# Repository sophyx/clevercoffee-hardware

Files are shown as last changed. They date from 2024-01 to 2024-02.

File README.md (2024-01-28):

# Fork from [clevercoffee-hardware](https://github.com/rancilio-pid/clevercoffee-hardware)

Forked because I want to improve the routing of the minimal PCB. Original Readme:

# CleverCoffee Hardware 

<br>

KiCAD projects for breakout boards based on the ESP32 DevKitC v4 

* Minimal PCB with a smaller footprint and all unused GPIO-Pins on a separate header
* Development PCB with additional support for rotary encoder and dimmer circuit
* Experimental SMD variant of the minimal PCB with additional headers for the optional brew and steam LEDs
* Experimental SMD variant of the development PCB with a smaller footprint and wider spacing of the headers to be able to mount JST XH plugs

<br>
If you want to order PCBs yourself please keep in mind that the development boards are still a work in progress. The pinmapping for the features that are not yet on the minimal PCB is subject to change at any time.
<br>
<br>
For the latest revision of the minimal PCB just write us a message on our Discord.
<br>
<br>
If you want to create your own hardware based on our designs, please contact us beforehand to make sure you're not developing against an outdated revision. There may be unpublished changes not yet available in the repository.<br>
Also note that for regulatory and safety reasons we are not interested in designs with components operating at mains voltage.
<br>
<br>

Creative Commons Licence

<br>
<br>



This work is licensed under a <a rel="license" href="http://creativecommons.org/licenses/by-nc-sa/4.0/">Creative Commons Attribution-NonCommercial-ShareAlike 4.0 International License</a>

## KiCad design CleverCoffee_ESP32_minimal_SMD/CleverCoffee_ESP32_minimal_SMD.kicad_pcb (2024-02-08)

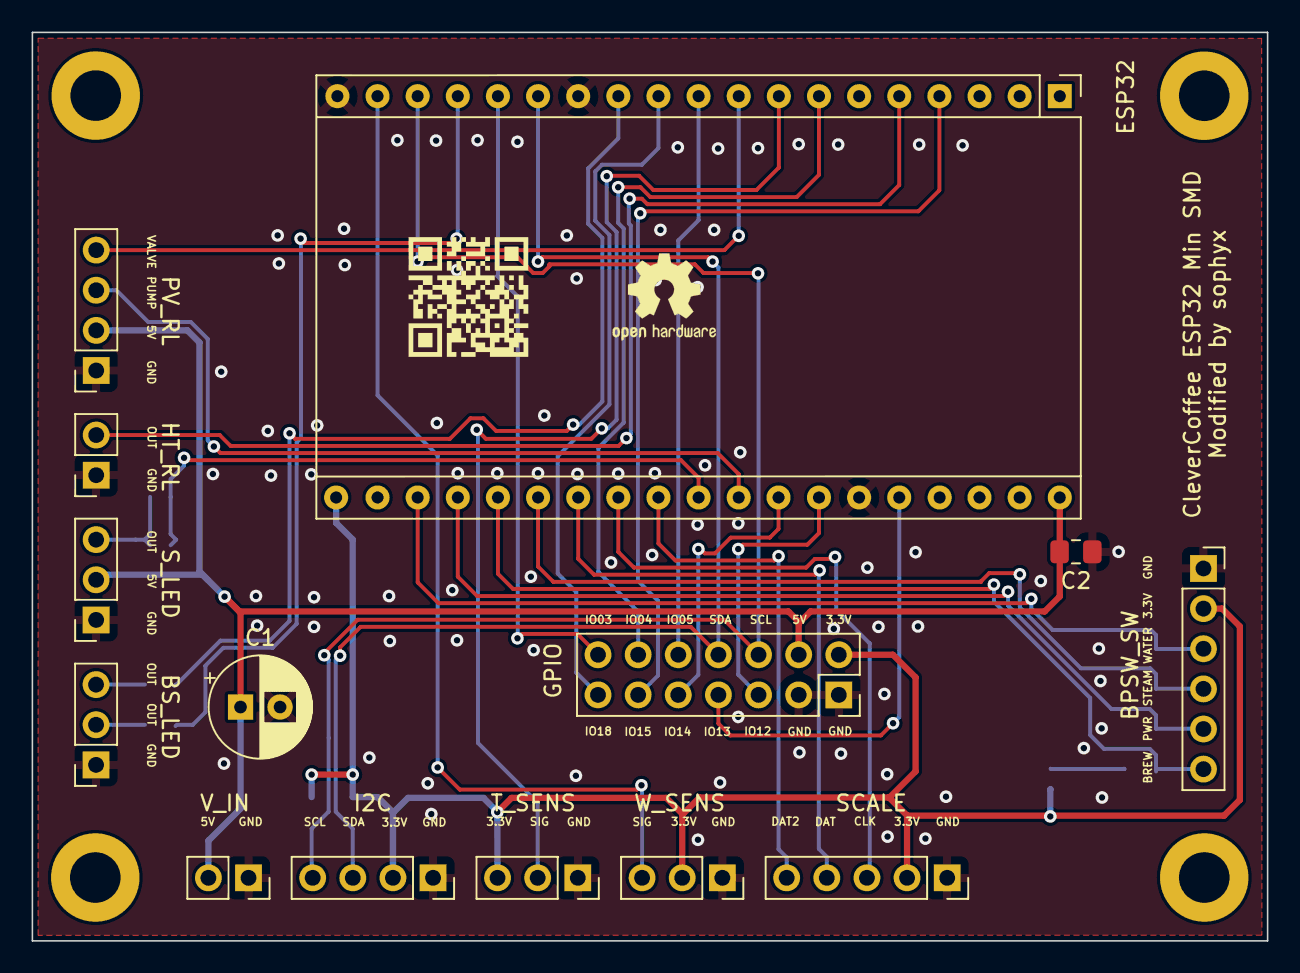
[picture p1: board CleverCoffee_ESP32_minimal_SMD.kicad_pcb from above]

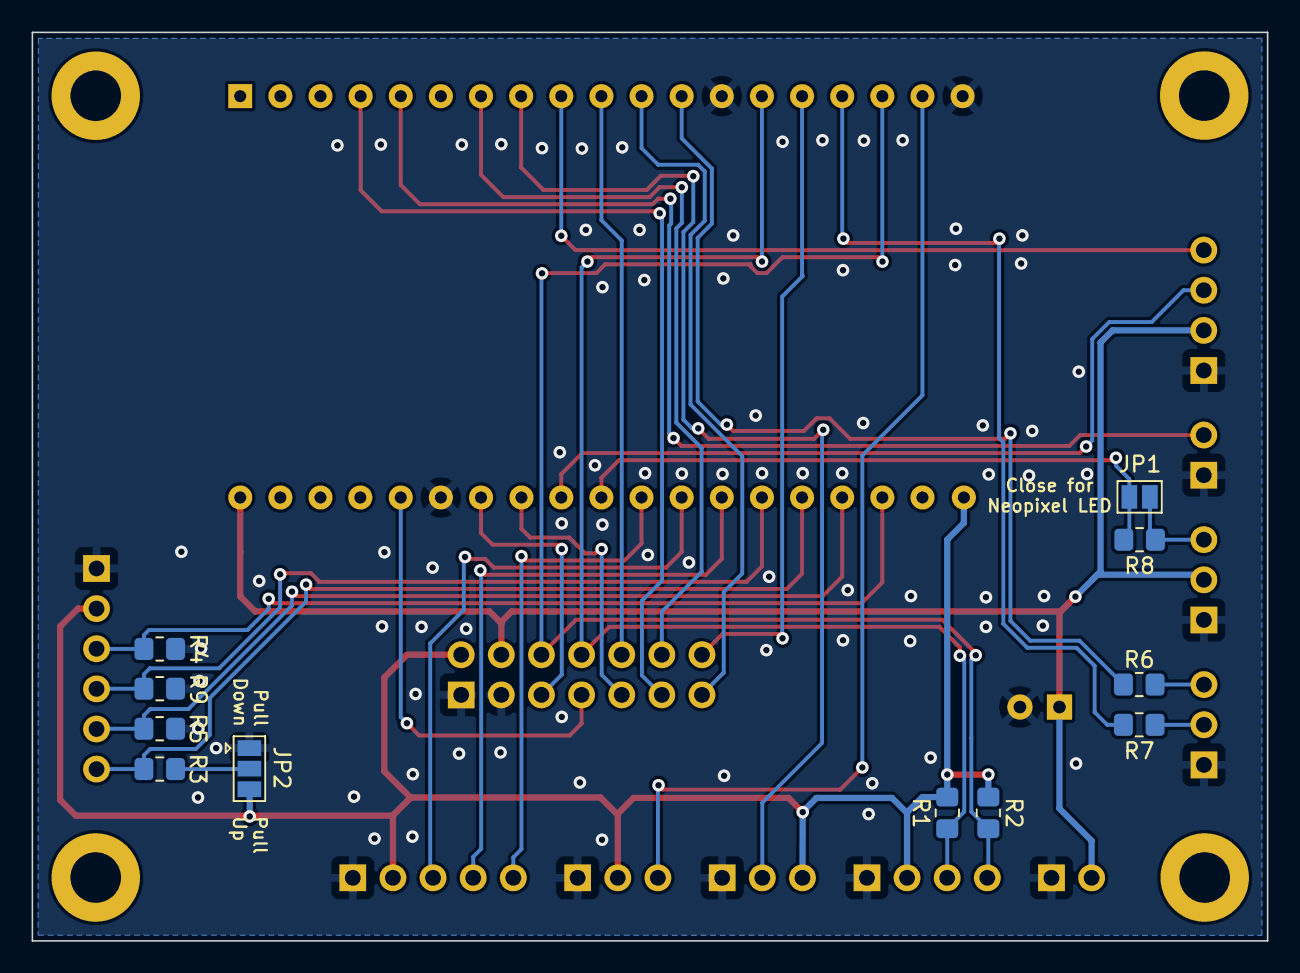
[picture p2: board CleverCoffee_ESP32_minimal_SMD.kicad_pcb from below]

Board: 2 copper layers, 78.2 x 57.5 mm, 29 parts (11 on the bottom side), 32 nets.

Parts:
BPSW_SW: Conn_01x05; PinSocket_1x06_P2.54mm_Vertical
BS_LED: Conn_01x02; PinSocket_1x03_P2.54mm_Vertical
C1: 220 μF; CP_Radial_D6.3mm_P2.50mm
C2: 100 nF; C_0805_2012Metric_Pad1.18x1.45mm_HandSolder
ESP32: NodeMCU_DevKitC_v4; NodeMCU DevKitC v4
GPIO: Conn_02x07_Counter_Clockwise; PinSocket_2x07_P2.54mm_Vertical
H1, H2, H3, H4: MountingHole_3.2mm_M3_DIN965_Pad
HT_RL: Conn_01x02; PinSocket_1x02_P2.54mm_Vertical
I2C: Conn_01x04; PinSocket_1x04_P2.54mm_Vertical
JP1: SolderJumper_2_Open; SolderJumper-2_P1.3mm_Open_Pad1.0x1.5mm
JP2: SolderJumper_3_Open; SolderJumper-3_P1.3mm_Open_Pad1.0x1.5mm
PV_RL: Conn_01x04; PinSocket_1x04_P2.54mm_Vertical
R1, R2: 4K7 Ω; R_0805_2012Metric_Pad1.20x1.40mm_HandSolder
R3, R4, R5, R9: 47K Ω; R_0805_2012Metric_Pad1.20x1.40mm_HandSolder
R6, R7, R8: 220 Ω; R_0805_2012Metric_Pad1.20x1.40mm_HandSolder
SCALE: Conn_01x05; PinSocket_1x05_P2.54mm_Vertical
S_LED: Conn_01x03; PinSocket_1x03_P2.54mm_Vertical
T_SENS: Conn_01x03; PinSocket_1x03_P2.54mm_Vertical
V_IN: Conn_01x02; PinSocket_1x02_P2.54mm_Vertical
W_SENS: Conn_01x03; PinSocket_1x03_P2.54mm_Vertical

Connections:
+3V3: BPSW_SW.2, ESP32.20 (3V3), GPIO.2, I2C.2, JP2.3 (B), R1.2, R2.2, SCALE.2, T_SENS.3, W_SENS.2
+5V: C1.1, C2.1, ESP32.38 (VDD), GPIO.4, PV_RL.2, S_LED.2, V_IN.2
CLK: ESP32.27 (IO33), SCALE.3
DAT: ESP32.26 (IO32), SCALE.4
DAT2: ESP32.28 (IO25), SCALE.5
GND: BPSW_SW.1, BS_LED.1, C1.2, C2.2, ESP32.13 (GND), ESP32.19 (GND), ESP32.33 (GND), GPIO.1, GPIO.3, HT_RL.1, I2C.1, JP2.1 (A), PV_RL.1, R4.2, R5.1, R9.2, SCALE.1, S_LED.1, T_SENS.1, V_IN.1, W_SENS.1
IO1: ESP32.16 (IO1/Tx), R7.2
IO2: ESP32.5 (IO2), HT_RL.2
IO3: ESP32.15 (IO3/Rx), GPIO.14
IO4: ESP32.7 (IO4), GPIO.12
IO5: ESP32.10 (IO5), GPIO.10
IO12: ESP32.32 (IO12/TDI), GPIO.5
IO13: ESP32.34 (IO13/TCK), GPIO.7
IO14: ESP32.31 (IO14/TMS), GPIO.9
IO15: ESP32.4 (IO15/TDO), GPIO.11
IO16: ESP32.8 (IO16/Rx2), T_SENS.2
IO18: ESP32.11 (IO18), GPIO.13
IO19: ESP32.12 (IO19), R6.2
IO23: ESP32.18 (IO23), W_SENS.3
IO26: ESP32.29 (IO26), JP1.2 (B), R8.2
IO34: BPSW_SW.6, ESP32.24 (IO34), R3.2
IO35: BPSW_SW.4, ESP32.25 (IO35), R9.1
IO36: BPSW_SW.3, ESP32.22 (IO36), R4.1
IO39: BPSW_SW.5, ESP32.23 (IO39), R5.2
unnamed: BS_LED.2, R7.1
unnamed: BS_LED.3, R6.1
unnamed: JP1.1 (A), R8.1, S_LED.3
unnamed: JP2.2 (C), R3.1
PUMP: ESP32.30 (IO27), PV_RL.3
SCL: ESP32.17 (IO22/SCL), GPIO.6, I2C.4, R2.1
SDA: ESP32.14 (IO21/SDA), GPIO.8, I2C.3, R1.1
VALVE: ESP32.9 (IO17/Tx2), PV_RL.4

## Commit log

2024-01-28 mirrored pin headers to correct GND pad, changed SMD footprints to 0805 and rearranged SMD parts
    [CleverCoffee_ESP32_minimal_SMD.kicad_pcb, CleverCoffee_ESP32_minimal_SMD.kicad_sch]
2024-01-30 first routing draft
    [CleverCoffee_ESP32_minimal_SMD.kicad_pcb]
2024-02-08 improved routing, added gnd plane stitching
    [CleverCoffee_ESP32_minimal_SMD.kicad_pcb]

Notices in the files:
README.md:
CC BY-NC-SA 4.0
